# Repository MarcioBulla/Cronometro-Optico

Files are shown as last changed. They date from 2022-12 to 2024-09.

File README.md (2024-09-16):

# Photogate_V2
I recomend use the second version (improve precise, security, 3D model, interface and schematic): 
https://github.com/Lorxi3D/PhotogateV2

# Objetivo

- [x] Programar o Esp32 com interface para cada experimento, assim facilitando o aluno realizar os experimentos;
- [x] Criar um diagrama e um modelo 3D do Circuito; 
- [x] Modelar 3D todo o projeto, para uma impressão 3D;
- [x] Publica trabalho (doi.org/10.1088/1361-6552/ad6d23).

# Bibliotecas usadas
- `encoder_menu.py`: https://github.com/MarcioBulla/encodermenu
- `rotary.py` e `rotary_irq_esp.py`: https://github.com/miketeachman/micropython-rotary

# Montagem
[Lista de itens e montagem](http://htmlpreview.github.io/?https://github.com/MarcioBulla/Cronometro-Optico/blob/main/manual/Item_List.html)

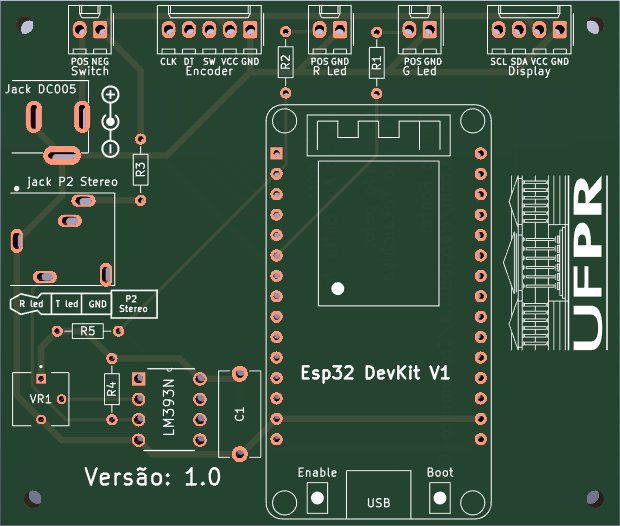
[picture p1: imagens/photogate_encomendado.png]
Imagem sem componente


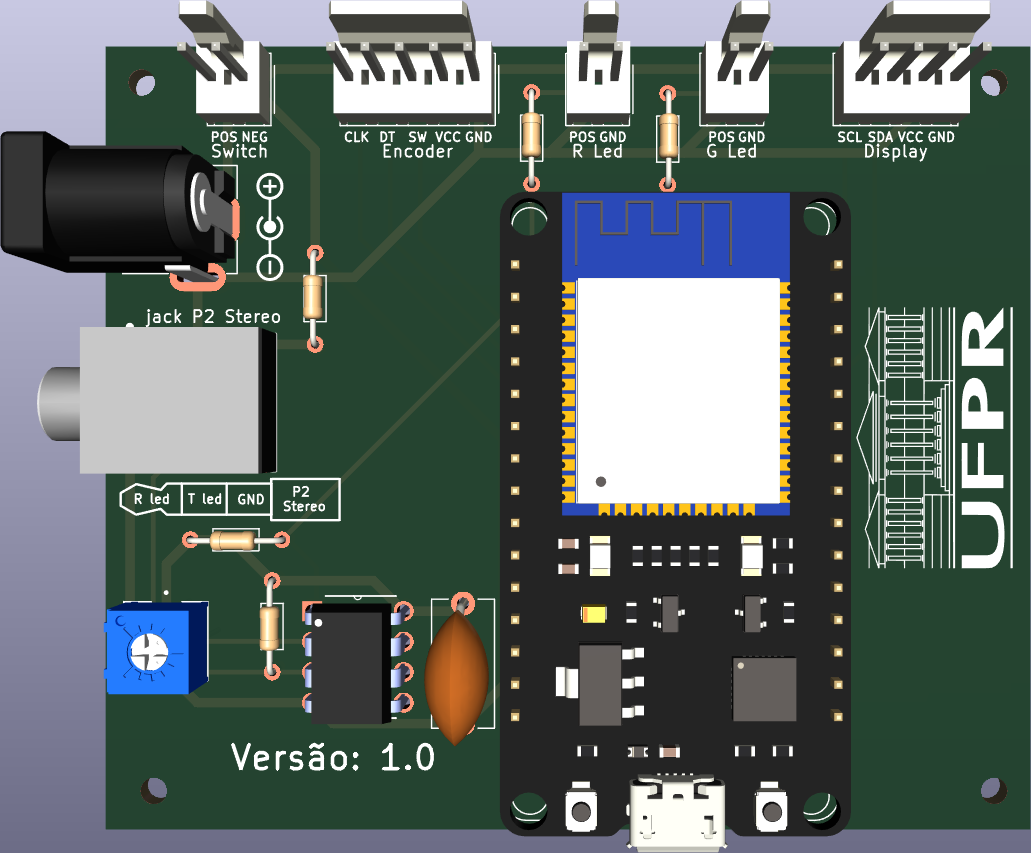
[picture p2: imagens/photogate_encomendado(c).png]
Imagem com componente


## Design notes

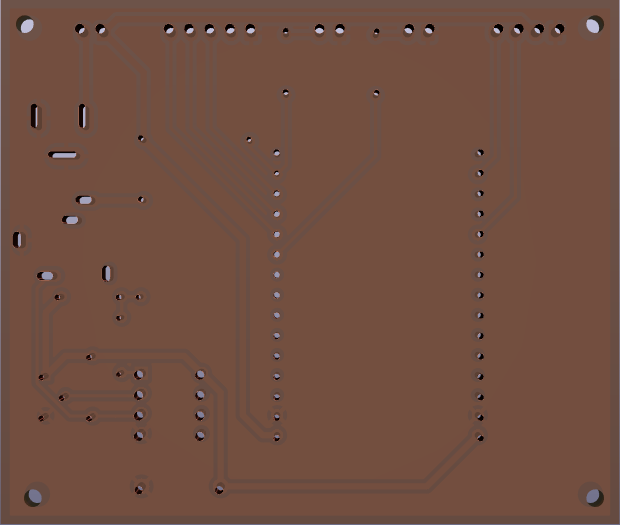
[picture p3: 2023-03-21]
imagens/photogate_fenolite.png

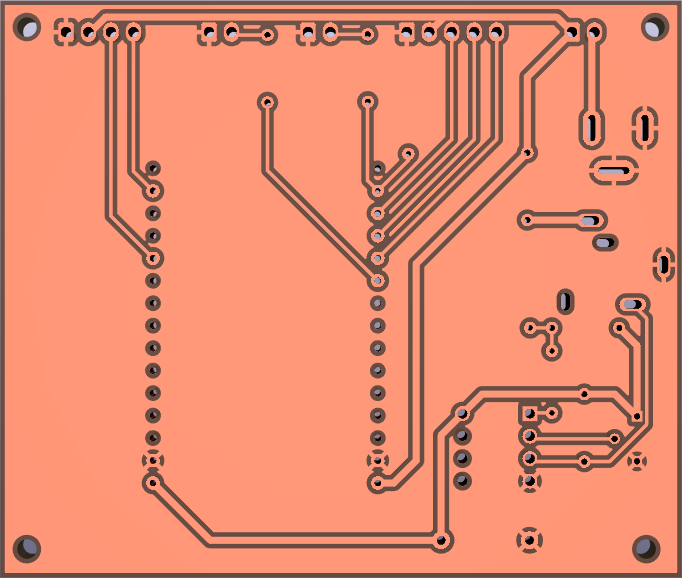
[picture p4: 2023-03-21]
imagens/photogate_fenolite(b).png

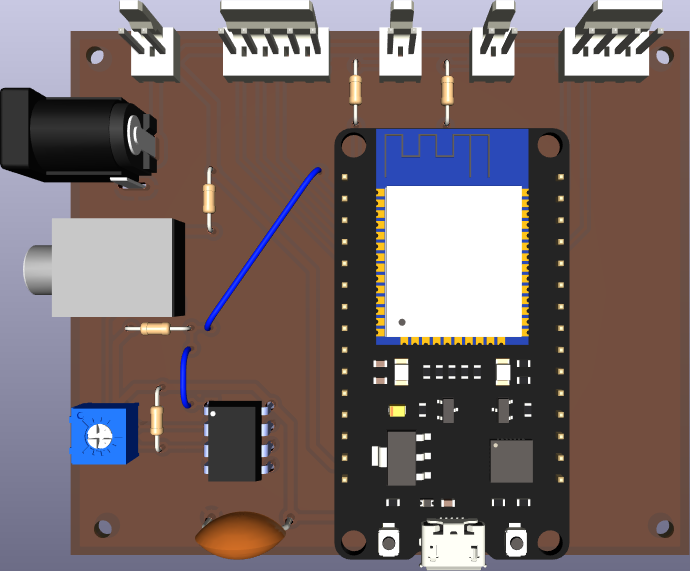
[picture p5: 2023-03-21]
imagens/photogate_fenolite(c).png

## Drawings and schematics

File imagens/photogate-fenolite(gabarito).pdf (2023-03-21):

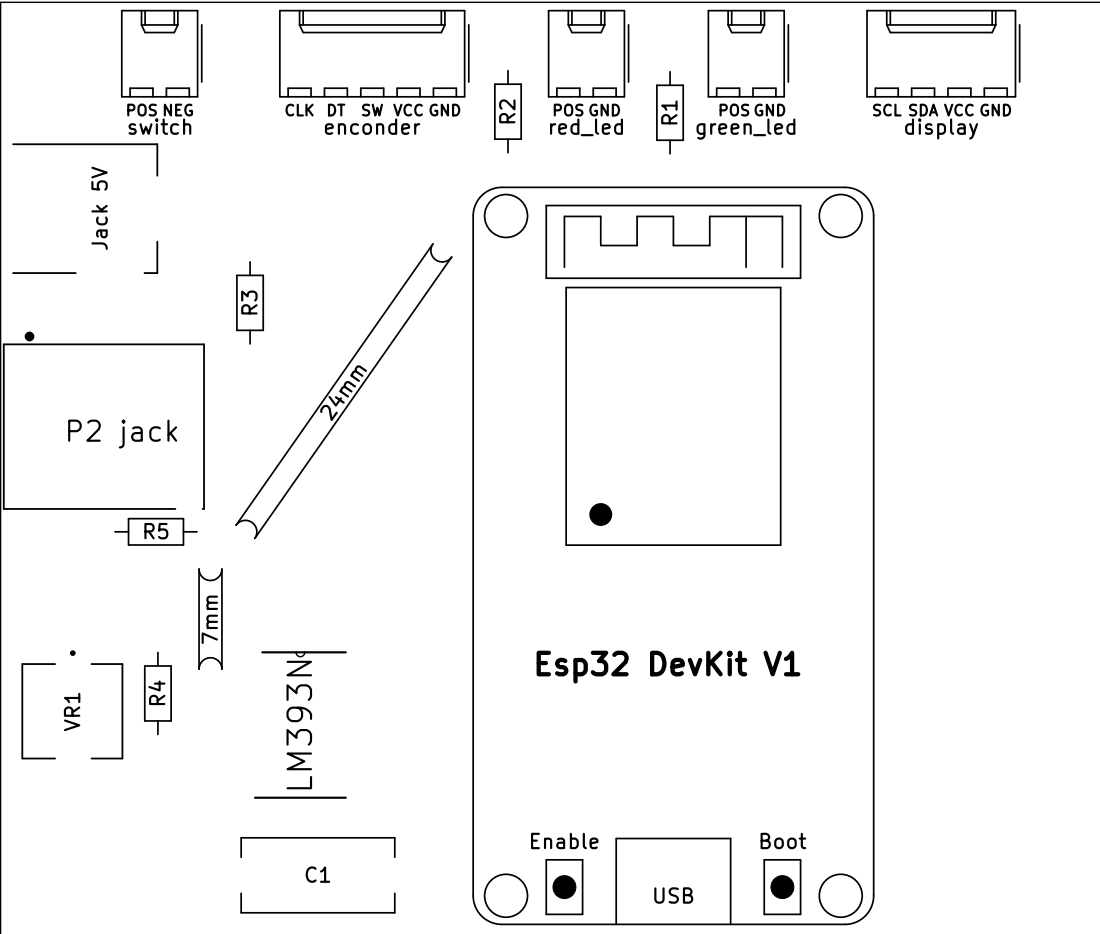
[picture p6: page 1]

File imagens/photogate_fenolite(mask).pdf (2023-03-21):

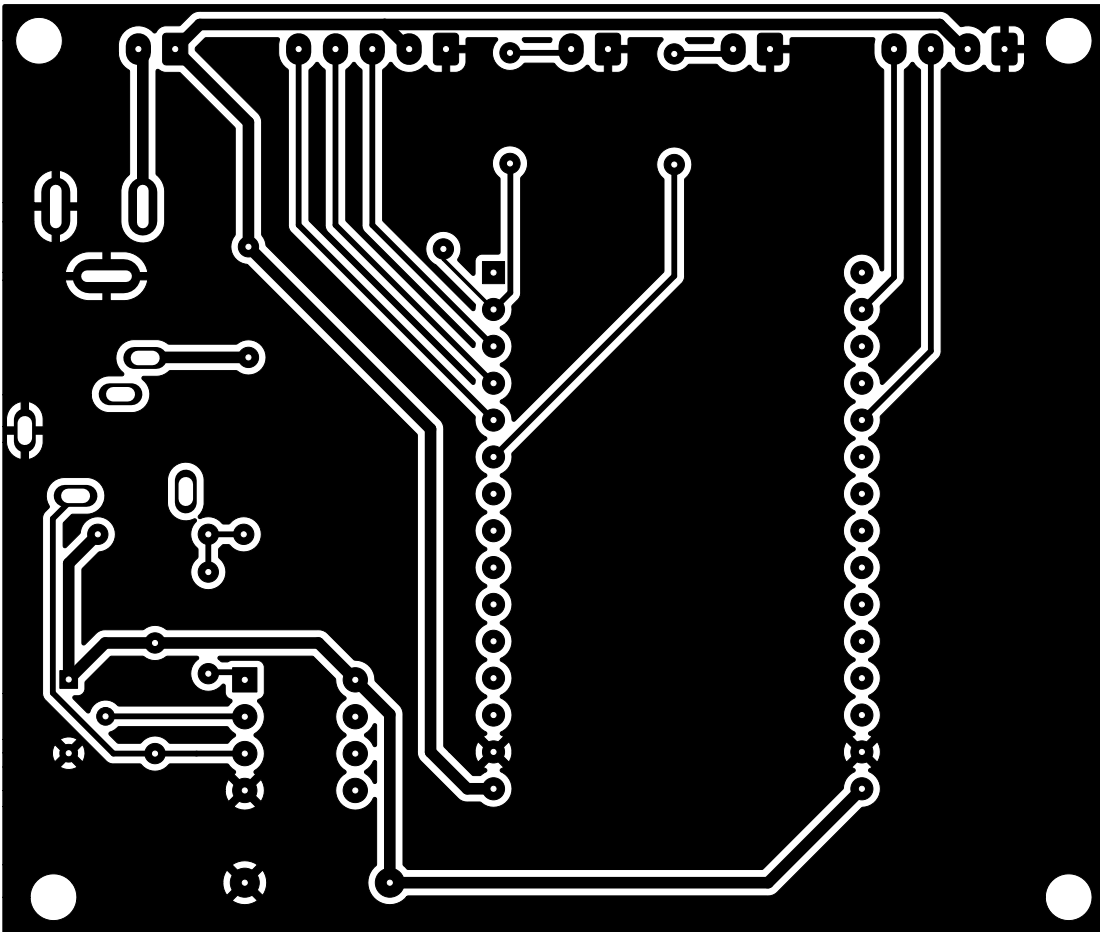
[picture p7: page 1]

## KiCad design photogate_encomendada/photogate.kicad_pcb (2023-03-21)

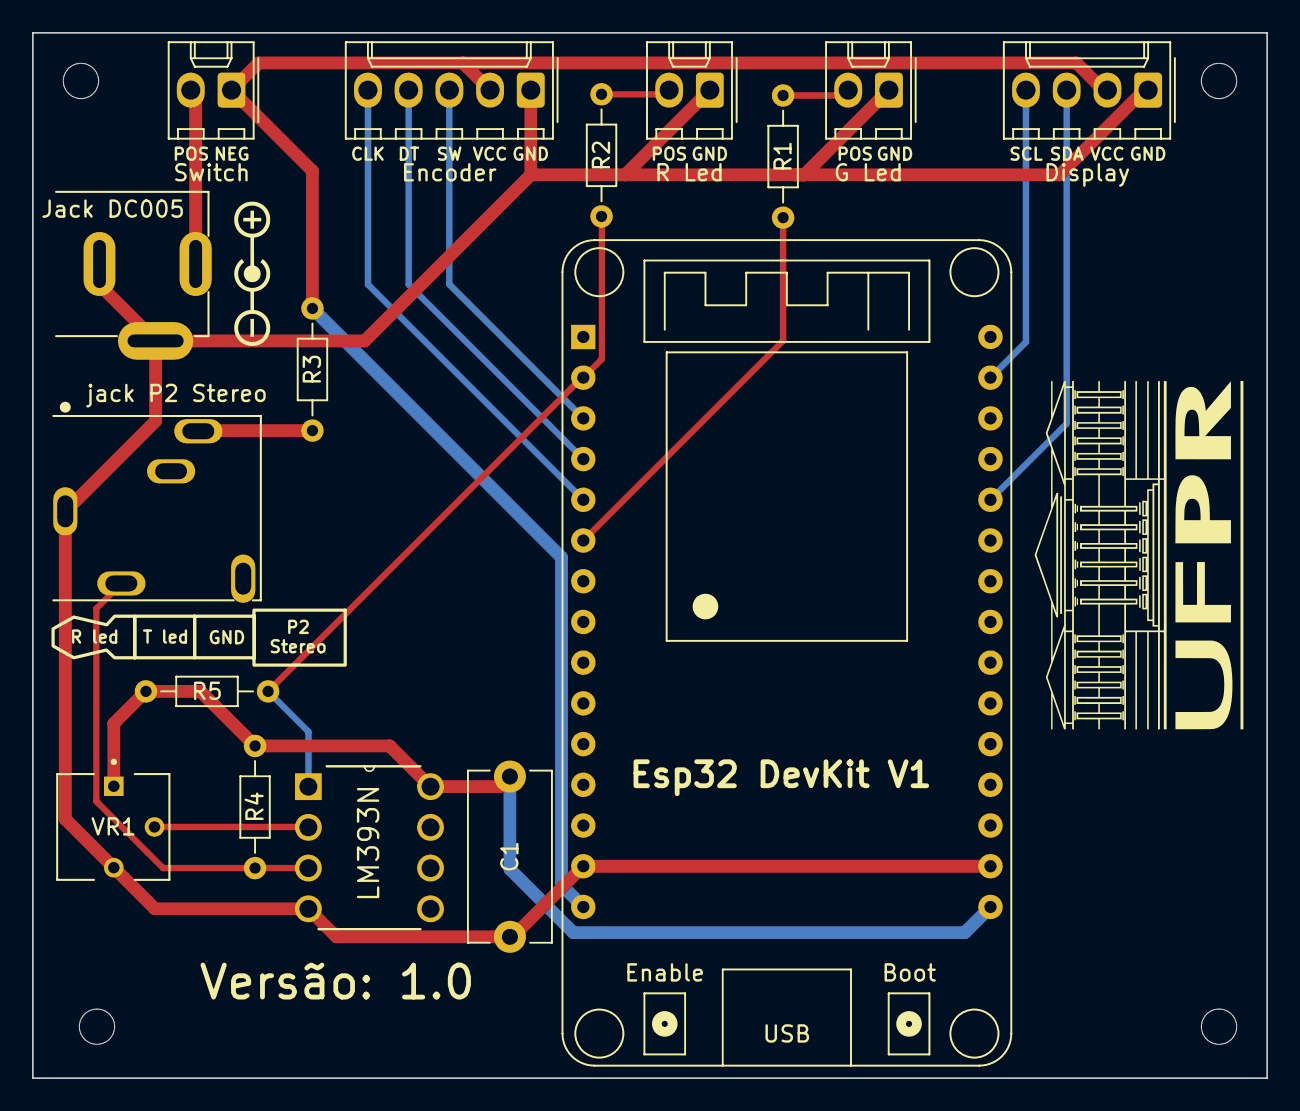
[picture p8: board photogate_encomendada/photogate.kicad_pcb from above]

Board: 2 copper layers, 77.0 x 65.2 mm, 23 parts (0 on the bottom side), 16 nets.

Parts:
C1: 104k; C_Disc_D10.5mm_W5.0mm_P10.00mm
Display: Conn_01x04_Female; Molex_KK-254_AE-6410-04A_1x04_P2.54mm_Vertical
Encoder: Conn_01x05_Female; Molex_KK-254_AE-6410-05A_1x05_P2.54mm_Vertical
Esp32 DevKit V1: ESP32_DevKit_V1_DOIT; esp32_devkit_v1_doit
Furo Central: MountingHole_2.2mm_M2
Furo Inferior1, Furo Inferior2: MountingHole_2.2mm_M2
Furo Superior: MountingHole_2.2mm_M2
G Led: Conn_01x02_Female; Molex_KK-254_AE-6410-02A_1x02_P2.54mm_Vertical
Jack DC005: DC-005; NINIGI_DC-005
LM393N: LM393N1; LM393N
P2 3poles: LOGO; P2_3poles
R1, R2, R3, R5: 100; R_Axial_DIN0204_L3.6mm_D1.6mm_P7.62mm_Horizontal
R4: 10k; R_Axial_DIN0204_L3.6mm_D1.6mm_P7.62mm_Horizontal
R Led: Conn_01x02_Female; Molex_KK-254_AE-6410-02A_1x02_P2.54mm_Vertical
Switch: Conn_01x02_Female; Molex_KK-254_AE-6410-02A_1x02_P2.54mm_Vertical
UFPR: UFPR
VR1: 3362P-1-103; TRIM_3362P-1-103
jack P2 Stereo: SJ1-3515N; CUI_SJ1-3515N
polarity: Symbol; Polarity_Center_Positive_9mm_SilkScreen

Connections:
/CLK: Encoder.5, Esp32 DevKit V1.5 (IO35)
/D0: Esp32 DevKit V1.2 (SENSOR_VP), LM393N.1 (Output), R2.1, R5.1
/DT: Encoder.4, Esp32 DevKit V1.4 (IO34)
/FUNC_LED: G Led.2, R1.2
/PHOTODIODE: LM393N.3 (+), R4.2, jack P2 Stereo.2
/SCL: Display.4, Esp32 DevKit V1.29 (IO22)
/SDA: Display.3, Esp32 DevKit V1.26 (IO21)
/SW: Encoder.3, Esp32 DevKit V1.3 (SENSOR_VN)
GND: C1.2, Display.1, Encoder.1, Esp32 DevKit V1.14 (GND), Esp32 DevKit V1.17 (GND), G Led.1, Jack DC005.2, Jack DC005.3, LM393N.4 (V-), R Led.1, VR1.3, jack P2 Stereo.1
unnamed: C1.1, Esp32 DevKit V1.16 (3V3), LM393N.8 (V+), R4.1, R5.2, VR1.1
unnamed: Esp32 DevKit V1.6 (IO32), R1.1
unnamed: Display.2, Encoder.2, Esp32 DevKit V1.15 (VIN), R3.1, Switch.1
unnamed: Jack DC005.4, Switch.2
unnamed: LM393N.2 (-), VR1.2
unnamed: R2.2, R Led.2
unnamed: R3.2, jack P2 Stereo.3

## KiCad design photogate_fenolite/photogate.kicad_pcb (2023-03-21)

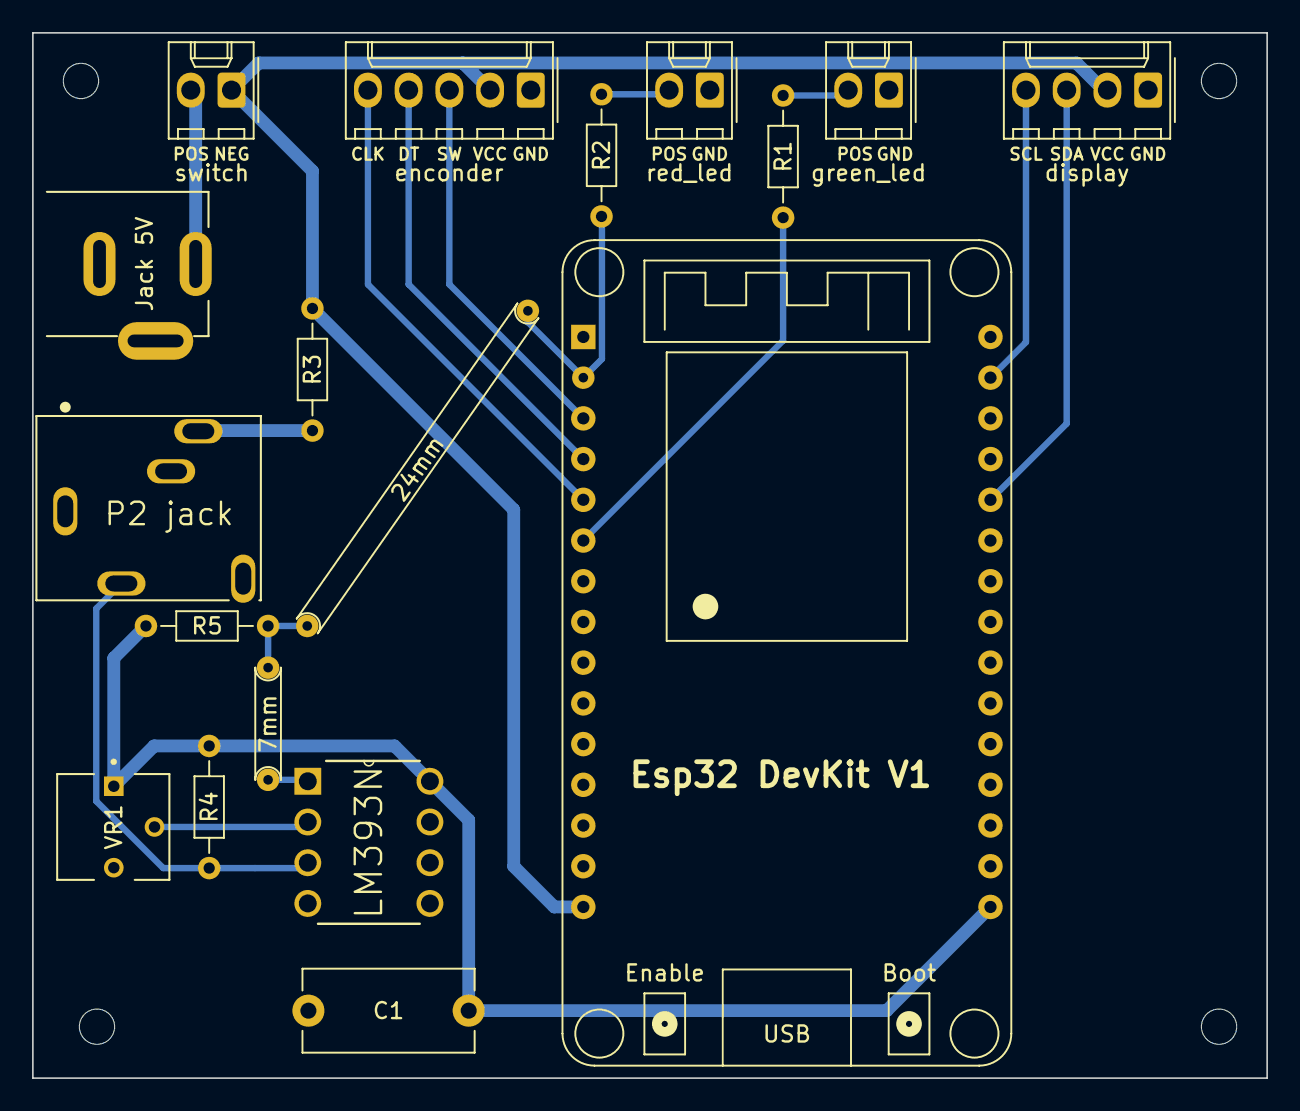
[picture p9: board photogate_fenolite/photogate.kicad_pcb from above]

Board: 2 copper layers, 77.0 x 65.2 mm, 22 parts (0 on the bottom side), 18 nets.

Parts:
5mm: Jumper_7mm; Jumper_7mm_blue
24mm: Jumper_24mm; Jumper_24mm_blue
C1: 104k; C_Disc_D10.5mm_W5.0mm_P10.00mm
Esp32 DevKit V1: ESP32_DevKit_V1_DOIT; esp32_devkit_v1_doit
Furo Central: MountingHole_2.2mm_M2
Furo Inferior1, Furo Inferior2: MountingHole_2.2mm_M2
Furo Superior: MountingHole_2.2mm_M2
Jack 5V: DC-005
LM393N: LM393N1; LM393N
P2 jack: SJ1-3515N; CUI_SJ1-3515N
R1, R2, R3, R5: 100; R_Axial_DIN0204_L3.6mm_D1.6mm_P7.62mm_Horizontal
R4: 10k; R_Axial_DIN0204_L3.6mm_D1.6mm_P7.62mm_Horizontal
VR1: 3362P-1-103; trimpot_3362P
display: Conn_01x04_Female; Molex_KK-254_AE-6410-04A_1x04_P2.54mm_Vertical
enconder: Conn_01x05_Female; Molex_KK-254_AE-6410-05A_1x05_P2.54mm_Vertical
green_led: Conn_01x02_Female; Molex_KK-254_AE-6410-02A_1x02_P2.54mm_Vertical
red_led: Conn_01x02_Female; Molex_KK-254_AE-6410-02A_1x02_P2.54mm_Vertical
switch: Conn_01x02_Female; Molex_KK-254_AE-6410-02A_1x02_P2.54mm_Vertical

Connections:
/CLK: Esp32 DevKit V1.5 (IO35), enconder.5
/DT: Esp32 DevKit V1.4 (IO34), enconder.4
/FUNC_LED: R1.2, green_led.2
/PHOTODIODE: LM393N.3 (+), P2 jack.2, R4.2
/SCL: Esp32 DevKit V1.29 (IO22), display.4
/SDA: Esp32 DevKit V1.26 (IO21), display.3
/SW: Esp32 DevKit V1.3 (SENSOR_VN), enconder.3
GND: C1.2, Esp32 DevKit V1.14 (GND), Esp32 DevKit V1.17 (GND), Jack 5V.2, Jack 5V.3, LM393N.4 (V-), P2 jack.1, VR1.3, display.1, enconder.1, green_led.1, red_led.1
unnamed: C1.1, Esp32 DevKit V1.16 (3V3), LM393N.8 (V+), R4.1, R5.1, VR1.1
unnamed: 24mm.2 (B), Esp32 DevKit V1.2 (SENSOR_VP), R2.1
unnamed: Esp32 DevKit V1.6 (IO32), R1.1
unnamed: Esp32 DevKit V1.15 (VIN), R3.1, display.2, enconder.2, switch.1
unnamed: 5mm.1 (A), LM393N.1 (Output)
unnamed: Jack 5V.4, switch.2
unnamed: LM393N.2 (-), VR1.2
unnamed: P2 jack.3, R3.2
unnamed: R2.2, red_led.2
unnamed: 5mm.2 (B), 24mm.1 (A), R5.2

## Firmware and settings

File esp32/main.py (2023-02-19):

from encoder_menu import * 
from cronos import *
from ujson import load
from machine import freq
print(gc.mem_free(), gc.mem_alloc())

freq(240000000)

# set_data(key=, value=) 
with open("calibration.json", "r") as file:
    for key, value in load(file).items():
        set_data(key, value)

set_data("Pendulo", [])
set_data("Energy", [])
set_data("Mola", [])

# get_integer(low_v=, high_v=, increment=, caption=, field=)
# selection(field=, choices=)
# wizard funciona como um wrap_menu porem como uma sequencia de funções
# exemplo de wizard
# wizard([("Hours",sethours),("Minutes",setminutes),("Seconds",setseconds)])
print(menu_data)

BACK = ("Voltar", back)

# Pendulo
pend_config = get_integer(low_v=1, high_v=9, increment=1, caption="N"+chr(0)+" Periodos", field="pend_N")
pend_hist = hist(lcd, "Pendulo", "Hist: Pendulo")

## menu Pendulo
pend_menu = wrap_menu("Pendulo", [("START", pendulo()), ("Config", pend_config), ("Historico", pend_hist), BACK])


# Energia Mecanica
energy_config = selection("cylinder", ["Solido", "2R"+chr(4), "2R"+chr(3), "R"+chr(4)+"+"+"R"+chr(3)], "Tipos de medida")
energy_hist = hist(lcd, "Energy", "Hist: Energy")

## menu Energia Mecanica
energy_menu = wrap_menu("Energia Mecanica", [("START", energy()), ("Config", energy_config), ("Historico", energy_hist), BACK])


# Mola
mola_config = get_integer(low_v=1, high_v=9, increment=1, caption="N"+chr(0)+" Periodos", field="mola_N")
mola_hist = hist(lcd, "Mola", "Hist: Mola")

## menu Mola
mola_menu = wrap_menu("Mola", [("START", mola()), ("Config", mola_config), ("Historico", mola_hist), BACK])


# Calibragem
bias_dezena = get_integer(low_v=-100, high_v=100, increment=10, caption="Bias Dezena (ms)", field="bias", save=True)
bias_unidade = get_integer(low_v=-100, high_v=100, increment=1, caption="Bias Unidade (ms)", field="bias", save=True)
bias = wizard([("Bias Dezena",bias_dezena),("Bias Unidade (ms)",bias_unidade)])


# Criadores
criadores = info("Criado por:\n  Fabiano Yokaichiya\n  Marcio Bulla\n \nEm homenagem a um\ngrande amigo\n   Alisson Britto   \ndescanse em paz.")


## menu Calibragem
extra = wrap_menu("Extras", [("Calibragem Bias", bias), ("Desenvolvedores", criadores), BACK])


# Main Menu
main_menu = wrap_menu("Main Menu", [("Pendulo", pend_menu), ("Energia Mecanica",energy_menu), ("Mola", mola_menu), ("Extras", extra)])

# Start
main_menu()
run_menu() 

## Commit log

2022-11-12 Teste terminal (Problema range encoder)
    [main.py]
2022-11-12 Teste de funções (função blink)
2022-11-14 Atualização do projeto
    [montagem.fzz]
2022-11-16 1v do pendulo
2022-11-23 Priveira verição para Oled
2022-11-25 mais acabamentos para diplay oled
2022-12-02 Circuito em uma PCI
    [montagem.fzz, photogate.kicad_pcb, photogate.kicad_sch]
2022-12-02 Correção link para lista de materiais
2022-12-02 Add resitor green led
    [photogate.kicad_pcb, photogate.kicad_sch]
2022-12-04 Melhoras na placa
    [photogate.kicad_pcb, photogate.kicad_sch]
2022-12-04 add intruções na PCI
    [photogate.kicad_pcb]
2022-12-11 att designe PCB
    [photogate.kicad_pcb, photogate.kicad_sch]
2022-12-14 Add connector para switch
    [photogate.kicad_pcb, photogate.kicad_sch]
2022-12-15 Trocar connector jst para KK
    [photogate.kicad_pcb, photogate.kicad_sch]
2022-12-17 Ultimos ajustes
    [photogate.kicad_pcb, photogate.kicad_sch]
2023-03-21 Placas de fenolite e perfurada acabadas
    [photogate.kicad_pcb, photogate.kicad_sch]
